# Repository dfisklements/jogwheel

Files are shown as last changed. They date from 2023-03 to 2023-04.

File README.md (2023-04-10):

# jogwheel
Code and plans for a desktop jogwheel based on the qtpy rp2040 and an as6500 magnetic encoder

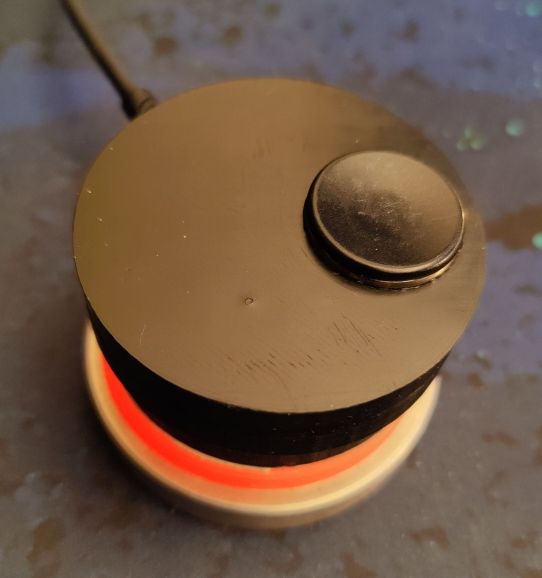
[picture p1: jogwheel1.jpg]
outside

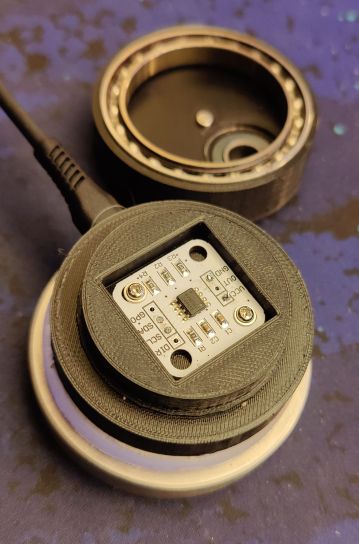
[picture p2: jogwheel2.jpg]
inside


## Hardware

QT-Py RP2040 ~ $10 <https://www.adafruit.com/product/4900>
- Small
- usb-C
- runs circuitpython (and others)
- can emulate an HID device
- has built in neopixel and stemma qt connector

AS-5600 magnetic encoder ~ $3
- Cheap!
- no moving parts
   - can be completely sealed
- uses i2c
- be sure to get one already in i2c mode, otherwise, you may have to customize the board a bit

6808ZZ ball Bearing ~ $10
- I had one lying around
- Nice size for a jog wheel
- Makes for really smooth action
  - Good feel for video scrubbing if degreased
  - Good feel for volume knob with stock grease

Misc other parts
- 608 bearing
- 3d printed body
- some clear material for translucent base section (can be 3dp as well)
- heavy base for stability (I used stainless)
- stemma qt connector (optional, you can solder instead)
- misc wires and soldering equipment

## assembly

- solder leads to as5600 and screw it to the base
  - standard i2c connections: vcc, gnd, sda, scl
  - I used some m2.5 screws, anything will work including hot glue.
- connect up the controller
- test before you finish assembly
  - usb connector spacing
  - firmware installed
  - encoder detected and working
- final assembly
  - I ended up trimming the wires pretty short
  - make sure the LED is face down so the light will show up through the translucent base
  - I hot-glued the qtpy in place, which makes it pletty durable, but semi-permenent.

## software

I completely tore apart a micropython as5600 library at first, but then I figured out how to just grab position via i2c directly.  this makes it pretty responsive, though I'm sure there is room for improvement

Currently I have it set to change modes every time the magnet is too far away from the sensor.  my wheel is pretty loose, so it seemed like a pretty logical way to change modes without adding any more complexity or parts.

## 3d print files

Included are a base and a top, as well as a spinner handle

The top and base will need to be printed with aligned seams, and will need to be filed down until they are pretty flat.  I did this manually with both sandpaper and with a file, both worked fine.

see stl folder for models

I printed mine on a prusa mk2s, and they came out great.

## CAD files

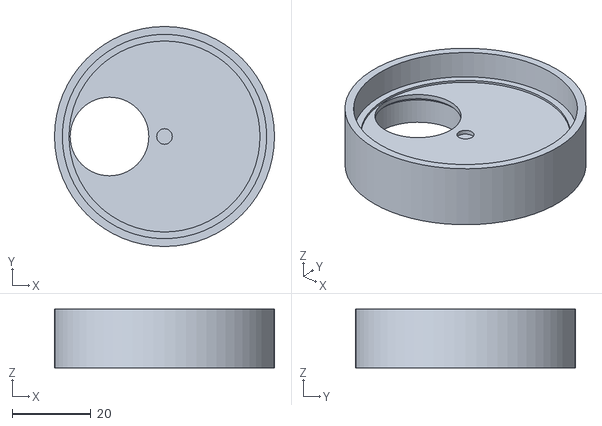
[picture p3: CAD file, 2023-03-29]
stl/jogwheel top.stl
56.0 x 56.0 x 15.0

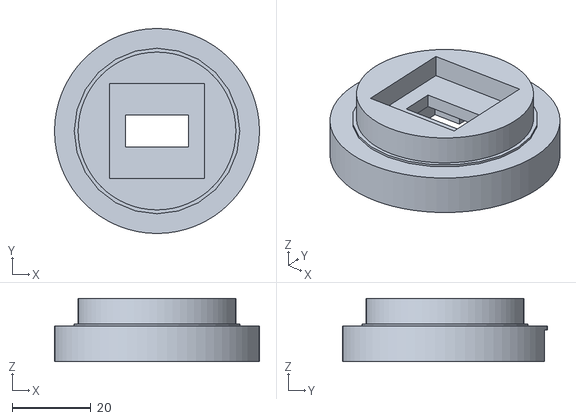
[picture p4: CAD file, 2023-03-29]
stl/jogwheel base.stl
52.0 x 52.0 x 16.0

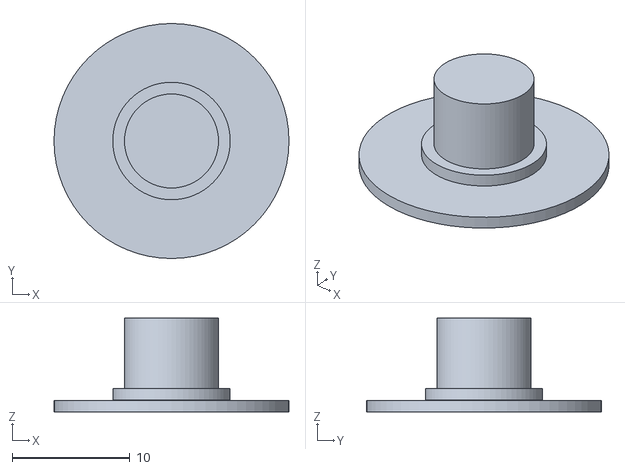
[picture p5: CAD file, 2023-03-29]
stl/spinner.stl
20.0 x 20.0 x 8.00

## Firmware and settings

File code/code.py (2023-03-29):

import board
import busio
import pwmio
from time import sleep
import usb_hid
import neopixel
import math
from adafruit_hid.mouse import Mouse
from adafruit_hid.keyboard import Keyboard
from adafruit_hid.keyboard_layout_us import KeyboardLayoutUS
from adafruit_hid.keycode import Keycode
from adafruit_hid.consumer_control import ConsumerControl

# configurables
threshold = round(4096/50)  # threshhold before triggering
delay = .005  # how long to sleep between loops
AS5600_id = 0x36

pixel = neopixel.NeoPixel(board.NEOPIXEL, 1)

i2c = board.STEMMA_I2C()

# Set up mouse and keyboard
cc = ConsumerControl(usb_hid.devices)
mouse = Mouse(usb_hid.devices)
keyboard = Keyboard(usb_hid.devices)
layout = KeyboardLayoutUS(keyboard)
shift = Keycode.SHIFT
ctrl = Keycode.CONTROL
alt = Keycode.ALT

l_actions = [
'keyboard.send(Keycode.LEFT_ARROW)',
'keyboard.send(ctrl, Keycode.LEFT_ARROW)',
'mouse.click(Mouse.LEFT_BUTTON)',
'mouse.move(wheel=1)',
'cc.send(234)'
]

r_actions = [
'keyboard.send(Keycode.RIGHT_ARROW)',
'keyboard.send(ctrl, Keycode.RIGHT_ARROW)',
'mouse.click(Mouse.LEFT_BUTTON)',
'mouse.move(wheel=-1)',
'cc.send(233)'
]

RED = (255, 0, 0)
YELLOW = (255, 150, 0)
GREEN = (0, 255, 0)
CYAN = (0, 255, 255)
BLUE = (0, 0, 255)
PURPLE = (180, 0, 255)

colors = (RED, YELLOW, BLUE, PURPLE, GREEN, CYAN)

max_modes = len(r_actions)
def right_action(velocity, mode):
    # print(f"({velocity})")
    maxreps = 5
    reps = round(abs(velocity)/threshold)
    reps = maxreps if reps > maxreps else reps
    for rep in range(0, reps, 1):
        eval(r_actions[mode])
    return

def left_action(velocity, mode):
    maxreps = 5
    reps = round(abs(velocity)/threshold)
    reps = maxreps if reps > maxreps else reps
    for rep in range(0, reps, 1):
        eval(l_actions[mode])
    return

def get_pos(i2c):
    while not i2c.try_lock():
        pass
    statusbytes = bytearray(1)
    positionbytes = bytearray(2)
    i2c.writeto_then_readfrom(AS5600_id, bytes([0x0b]), statusbytes)
    i2c.writeto_then_readfrom(AS5600_id, bytes([0x0e]), positionbytes)
    i2c.unlock()
    position = int.from_bytes(positionbytes, "big")
    status = int(bin(statusbytes[0])[3])
    # print(f'{position}, {status}')

    return status, int.from_bytes(positionbytes, "big")


# Main section
mode = -1
# initialize previous_angle
status, previous_angle = get_pos(i2c)
wheel_on = False

while True:
    status, angle = get_pos(i2c)
    if status and wheel_on:
        # normal jogging mode
        if abs(abs(angle) - abs(previous_angle)) > threshold:
            diff = angle - previous_angle
            if diff > 2048:
                left_action(diff - 4096, mode)
            elif diff < -2048:
                right_action(diff + 4096, mode)
            elif diff > threshold:
                right_action(diff, mode)
            elif diff < threshold:
                left_action(diff, mode)
            previous_angle = angle
    elif status and not wheel_on:
        # wheel has been reattached, possibly not in the same
        # orientation, so we prevent a big jump
        previous_angle = angle
        wheel_on = True
        mode = mode + 1
        if mode == max_modes:
            mode = 0

        pixel.fill(colors[mode])

    else:
        # wheel has been removed
        sleep(.25)
        previous_angle = angle
        wheel_on = False
        pixel.fill((10, 10, 10))

    sleep(delay)
